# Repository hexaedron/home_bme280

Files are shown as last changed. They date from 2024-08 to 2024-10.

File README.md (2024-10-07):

# home_bme280

A small 3-in-one thermometer, barometer and gigrometer for indoor use.
Built with ch32v003 MCU, BME280 sensor and vk16k33 i2c 14-segment display modules.

## Usage
When powered on, the device starts cycling through 3 screens: Temperature in Celsius, Humidity and air pressure in mm Hg.
* To set the brightness, rotate the encoder.
* To set the screen change interval, press and hold the encoder for 2+ seconds, choose the desired interval from 5s to 60 min and then click it again.
* To force the immediate screen change, click the encoder.

## Assembly
Assembly is pretty straightforward. You should just note that PCB is a little bit redundant. A first my idea was to add an LDR resistor, but i've abandoned that idea later. So you can omit R_LDR and J_LDR. The firmware doesn't use them.
I've also made some extra pins availiable as J_EXT. Feel free to use them to extend functionality if you want.

## Build
You will need [ch32v00fun](https://github.com/cnlohr/ch32v003fun/) and [funny_libs](https://github.com/hexaedron/funny_libs) to build it. I prefer using official WCH toolchain. If you prefer using vanilla risc-v GCC, then remove `#define WCH_FAST_INTERRUPT_ENABLED` from `funny_defs.h`.

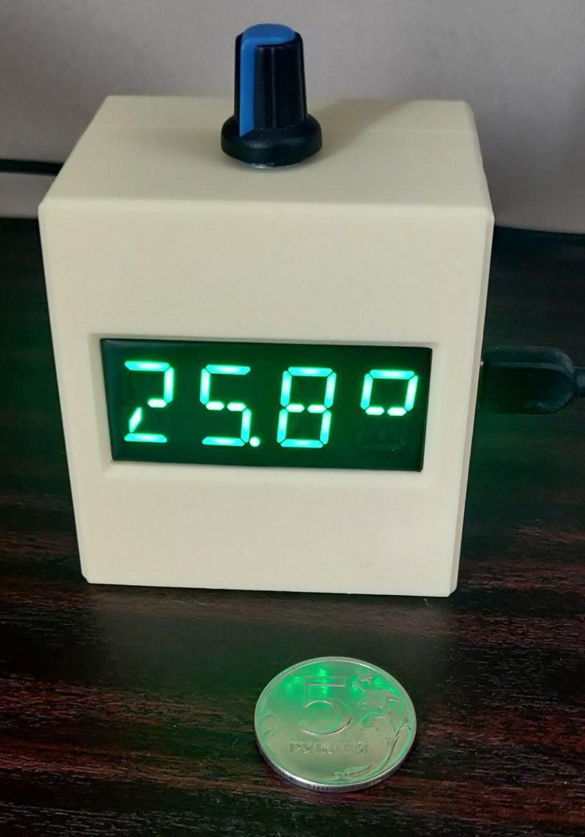
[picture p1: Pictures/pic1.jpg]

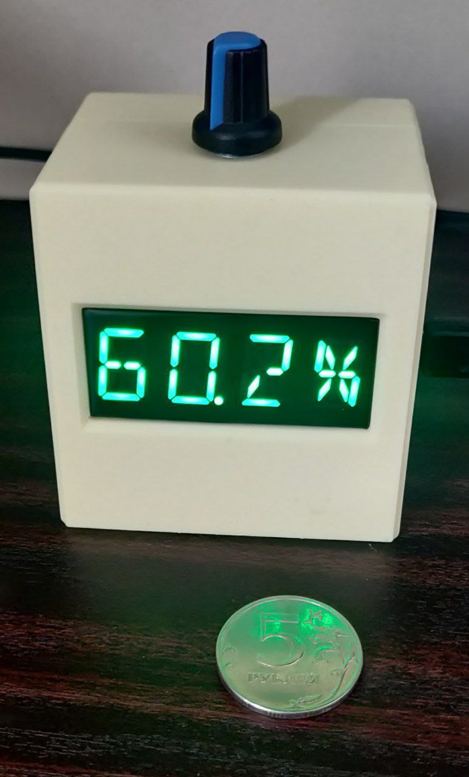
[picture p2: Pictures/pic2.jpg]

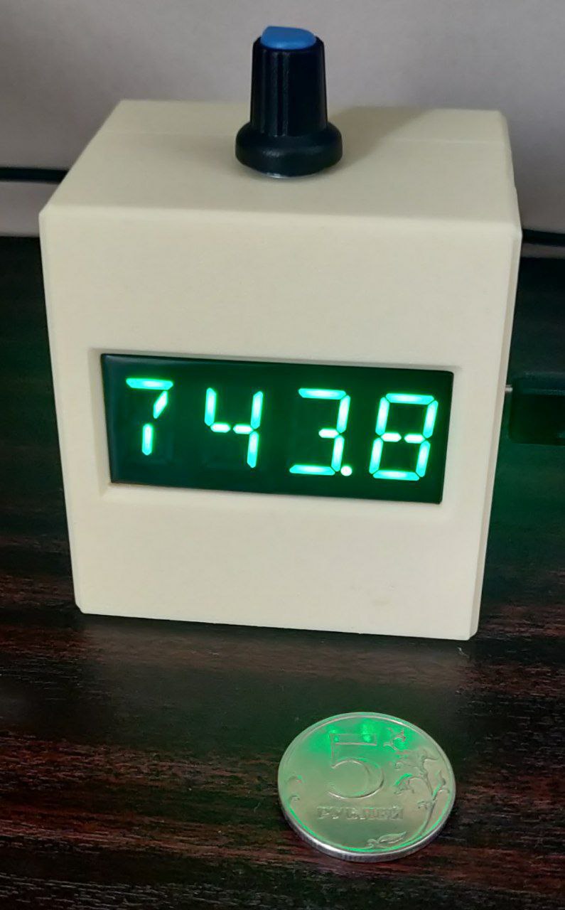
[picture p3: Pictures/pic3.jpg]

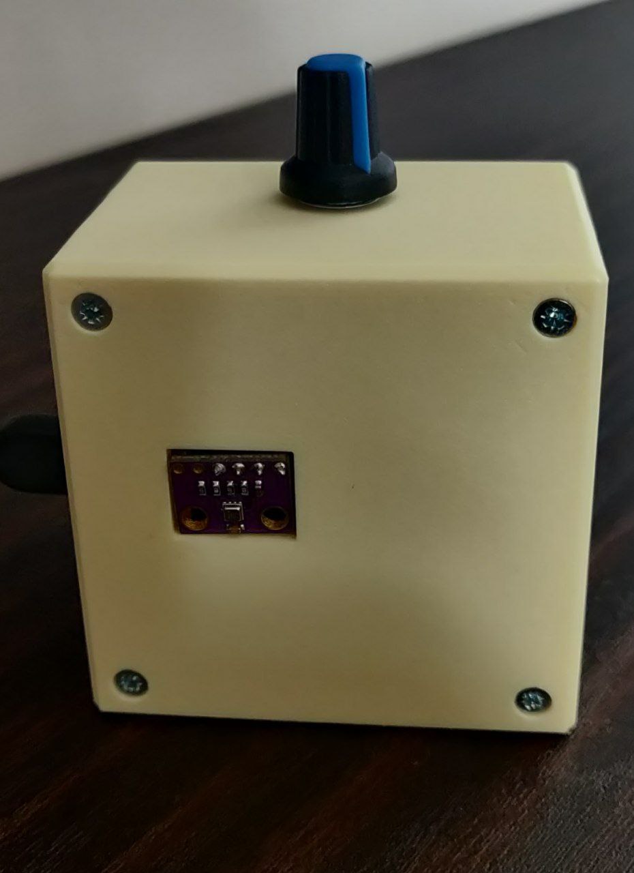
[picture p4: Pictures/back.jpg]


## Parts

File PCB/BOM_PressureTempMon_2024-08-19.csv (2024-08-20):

ID | Name | Designator | Footprint | Quantity | Manufacturer Part | Manufacturer | Supplier | Supplier Part | Price
1 | 10uF | C2,C6 | CASE-A_3216 | 2 | TCA1A106M8R | ROHM(罗姆) | LCSC | C184153 | 0.062
2 | 100nF | C5 | C1206 | 1 | C3216X7R2A104M160AA | TDK | LCSC | C3883507 | 0.455
3 | HDR-M-2.54_1x5 | ENCODER1,J_SCREEN | HDR-M-2.54_1X5 | 2 |  |  | LCSC | C358687 | 0.026
5 | HDR-M-2.54_1x2 | J_VCC | HDR-M-2.54_1X2 | 2 |  |  | LCSC | C124375 | 0.023
6 | HDR-M-2.54_1x3 | J_PRG1 | HDR-M-2.54_1X3 | 1 |  |  | LCSC | C180248 | 0.17
7 | HDR-M-2.54_1x4 | J_SENSOR | HDR-M-2.54_1X4 | 1 |  |  | LCSC | C124378 | 0.039
9 | CH32V003F4P6 | U5 | TSSOP-20_L6.5-W4.4-P0.65-LS6.4-BL | 1 | CH32V003F4P6 | null | LCSC | C5187096 | 0.258
10 | LM1117GS-3.3 | U_3 | SOT-223-3_L6.5-W3.4-P2.30-LS7.0-BR | 1 | LM1117GS-3.3 | HTC | LCSC | C411821 | 0.149
11 | Rotary encoder Arduino module (round),,,,,,,,

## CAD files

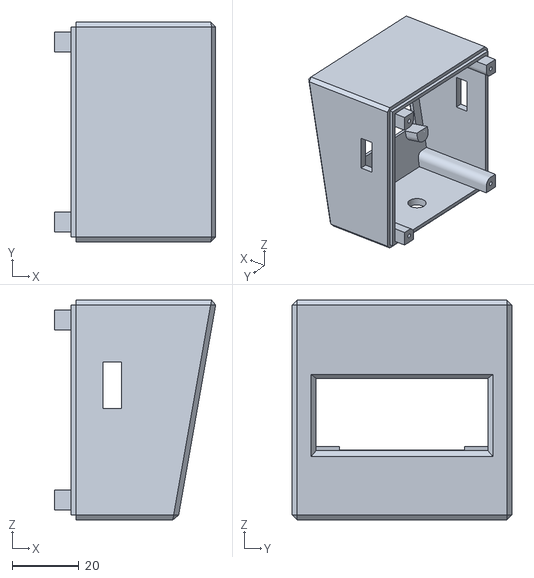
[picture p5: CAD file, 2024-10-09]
3DPrint/Front.stl
48.4 x 66.0 x 66.0

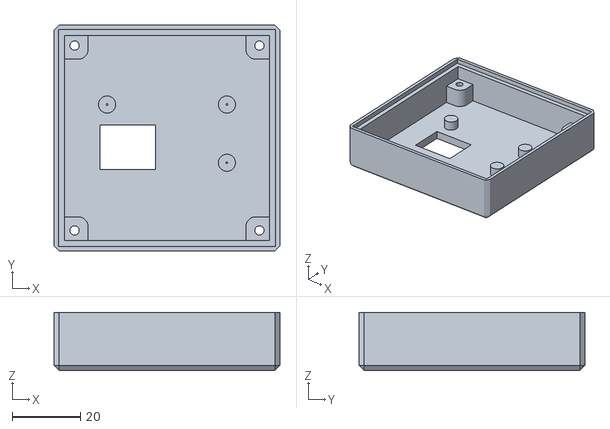
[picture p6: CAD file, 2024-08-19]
3DPrint/Back.stl
66.0 x 66.0 x 17.0

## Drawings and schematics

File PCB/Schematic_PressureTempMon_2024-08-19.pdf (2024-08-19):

# GND+⁵V

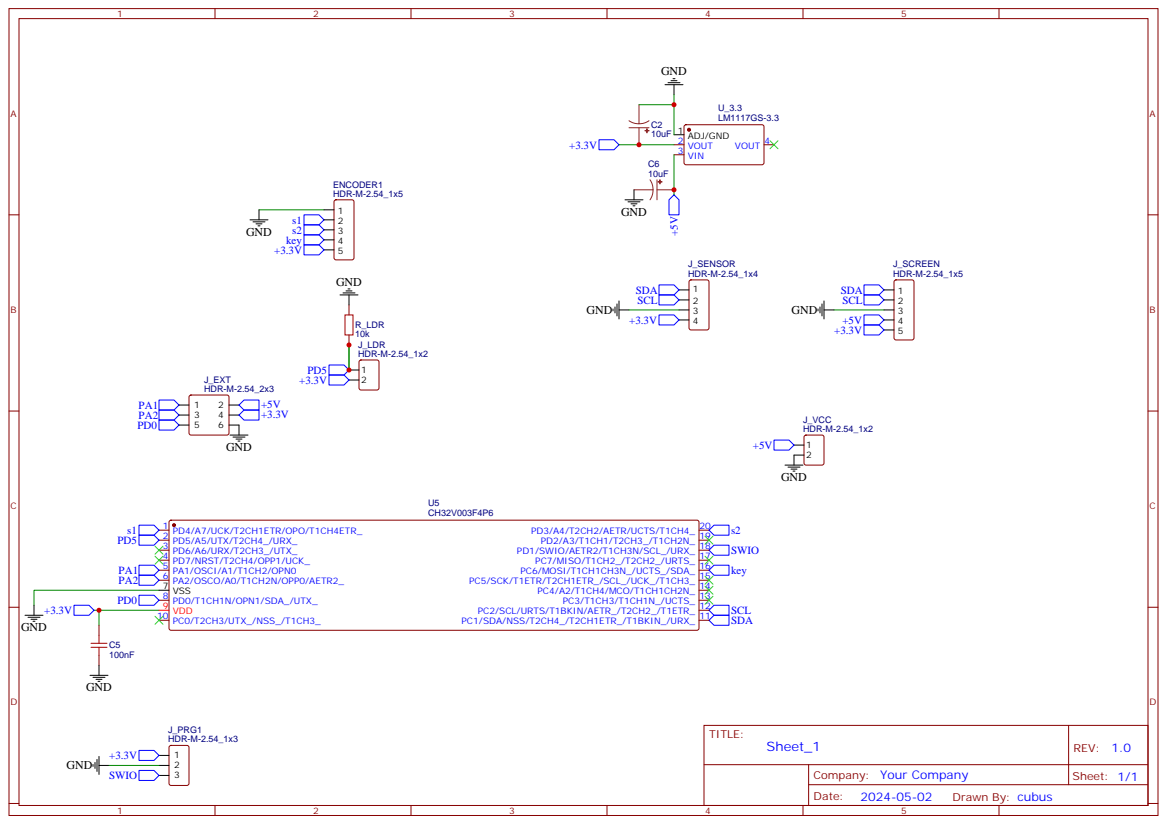
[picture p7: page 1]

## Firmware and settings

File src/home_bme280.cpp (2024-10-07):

#include <ch32v003fun.h>
#include "funny_defs.h"

#include "i2c_dma.h"
#include "BMP280.h"
#include "vk16k33.h"
#include "simpleTimer.h"
#include "tim2Encoder.h"
#include "optiondata.h"
#include "funny_time.h"

#include "pack_settings.h"

#include <stdbool.h>
#include <cstdlib>
#include <cstring>

enum displayMode_t
{
	printTemperature,
	printHumidity,
	printPressure
};

#define BRIGHTNESS_SAVE_TIMEOUT 5000UL
#define PRESSURE_HISTORY_HOURS  12

void setupMode(void);
int8_t getPressureTrend(uint32_t* pressureHistory, uint8_t pressureHistoryHours, uint32_t currentPressure);
void pushPressure(uint32_t* pressureHistory, uint8_t pressureHistoryHours, uint32_t currentPressure);

tim2Encoder enc(AFIO_PCFR1_TIM2_REMAP_NOREMAP);
vk16k33 screen;
uint16_t screenChangeSeconds_x5;
bool firstTime = true;

uint32_t pressureHistory[PRESSURE_HISTORY_HOURS] = {0};

int main()
{
	SystemInit();
#ifdef WCH_FAST_INTERRUPT_ENABLED
	__set_INTSYSCR(0x3); // [Experimental] enable fast interrupt feature
#endif
	system_initSystick();

	// We use button on PC6, so we need to init it and turn on interrupt.
	funGpioInitAll();
	funPinMode(PC6, GPIO_Speed_In | GPIO_CNF_IN_FLOATING);

	screenChangeSeconds_x5 = getScreenChangeSeconds_x5();

	bmp280 sensor;
	uint32_t pressure, humidity;
	int32_t temperature;

	// Accroding to vk16k33 datasheet, we need to wait until it wakes up.
	Delay_Ms(1); 

	I2C_init(400000, 0);

	sensor.init_default_params();
	sensor.init();

	screen.init();
	screen.setBrightness(getBrigtness());

	displayMode_t displayMode = displayMode_t::printTemperature;

	if( (screenChangeSeconds_x5 > 720) )
		screenChangeSeconds_x5 = 1;

	simpleTimer32 screenChangeTimer((uint32_t)screenChangeSeconds_x5 * 5000UL);
	simpleTimer32 flashTimer(BRIGHTNESS_SAVE_TIMEOUT);
	simpleTimer32 pressureHistoryTimer(3600UL * 1000UL);

	sensor.force_measurement();
	while (sensor.is_measuring())
	{
	};
	sensor.read_fixed();
	pressureHistory[PRESSURE_HISTORY_HOURS - 1] = sensor.getPressureMmHg();
	sensor.sleep();

	while (true)
	{
		keyTick();
		
		int delta = enc.getDelta();
		if(delta > 0)
		{
			screen.incBrightness();
			flashTimer.start_int();
		}
		if(delta < 0)
		{
			screen.decBrightness();
			flashTimer.start_int();
		}

		if(pressureHistoryTimer.ready())
		{
			sensor.force_measurement();
			while (sensor.is_measuring())
			{
			};
			sensor.read_fixed();
			pushPressure(pressureHistory, PRESSURE_HISTORY_HOURS, sensor.getPressureMmHg());
		}
		
		if(flashTimer.ready() && ((getBrigtness() != screen.getBrightness()) || (getScreenChangeSeconds_x5() != screenChangeSeconds_x5)))
		{
			uint8_t data0, data1;
			packSettings(screen.getBrightness(), screenChangeSeconds_x5, data0, data1);
			FlashOptionData(data0, data1);
			system_initSystick();
			screenChangeTimer.setPrd(screenChangeSeconds_x5 * 5000UL);
		}
		
		if(btnHeld())
		{
			setupMode();
		}

		bool wasClick = btnClick();
		if((screenChangeTimer.ready() || firstTime) || wasClick)
		{
			firstTime = false;
			if(wasClick) screenChangeTimer.start_int();
			wasClick = false;
			sensor.force_measurement();
			while (sensor.is_measuring())
			{
			};
			sensor.read_fixed();

			temperature = sensor.getTemp();
			humidity = sensor.getHumidity();
			pressure = sensor.getPressureMmHg();

			sensor.sleep();

			char buf[10];

			switch (displayMode)
			{
				case displayMode_t::printTemperature :
					itoa(temperature, buf, 10);
					if ((temperature > 0) && (temperature >= 1000))
					{
						screen.digit(ASCII_TO_INT(buf[0]), 0);
						screen.digit(ASCII_TO_INT(buf[1]), 1, true);
						screen.digit(ASCII_TO_INT(buf[2]), 2);
						screen.digit(10, 3);
					}
					else if((temperature > 0) && (temperature < 1000))
					{

						screen.digit(12, 0);
						screen.digit(ASCII_TO_INT(buf[0]), 1, true);
						screen.digit(ASCII_TO_INT(buf[1]), 2);
						screen.digit(10, 3);
					}
					screen.refresh();
					displayMode = displayMode_t::printHumidity;
				break;

				case displayMode_t::printHumidity :
					itoa(humidity, buf, 10);
					if(humidity >= 10000)
					{
						screen.digit(ASCII_TO_INT(buf[0]), 0);
						screen.digit(ASCII_TO_INT(buf[1]), 1, true);
						screen.digit(ASCII_TO_INT(buf[2]), 2);
					}
					else
					{
						screen.digit(12, 0);
						screen.digit(ASCII_TO_INT(buf[0]), 1, true);
						screen.digit(ASCII_TO_INT(buf[1]), 2);
					}
					screen.digit(11, 3);
					screen.refresh();
					displayMode = displayMode_t::printPressure;
				break;

				case  displayMode_t::printPressure :
					itoa(pressure / 256, buf, 10);
					screen.digit(ASCII_TO_INT(buf[0]), 0);
					screen.digit(ASCII_TO_INT(buf[1]), 1);
					screen.digit(ASCII_TO_INT(buf[2]), 2);
					switch (getPressureTrend(pressureHistory, PRESSURE_HISTORY_HOURS, pressure))
					{
						case 1:
							screen.digit(14, 3);
						break;

						case -1:
							screen.digit(13, 3);
						break;
					
						default:
							screen.digit(12, 3);
						break;
					}
					screen.refresh();
					displayMode = displayMode_t::printTemperature;
				break;
			
			default:
				break;
			}
		}
	}
}

void setupMode(void)
{
	simpleTimer32 refreshTimer(100UL);

	while (true)
	{
		keyTick();
		
		char buf[5];

		if(btnClick())
		{
			firstTime = true;
			return;
		}

		if(refreshTimer.ready())
		{
			uint8_t min = (screenChangeSeconds_x5 * 5) / 60;
			uint8_t sec = (screenChangeSeconds_x5 * 5) % 60;

			itoa(sec, buf, 10);
			if(sec > 0)
			{
				if(sec < 10)
				{
					screen.digit(0, 2);
					screen.digit(ASCII_TO_INT(buf[0]), 3);
				}
				else
				{
					screen.digit(ASCII_TO_INT(buf[0]), 2);
					screen.digit(ASCII_TO_INT(buf[1]), 3);
				}
			}
			else
			{
				screen.digit(ASCII_TO_INT(buf[0]), 2);
				screen.digit(ASCII_TO_INT(buf[0]), 3);
			}

			itoa(min, buf, 10);
			if(min < 10)
			{
				screen.digit(12, 0);
				screen.digit(ASCII_TO_INT(buf[0]), 1, true);
			}
			else
			{
				screen.digit(ASCII_TO_INT(buf[0]), 0);
				screen.digit(ASCII_TO_INT(buf[1]), 1, true);
			}

			screen.refresh();
		}

		int16_t delta = enc.getDelta();
		if(delta > 0)
		{
			if(screenChangeSeconds_x5 < 720)
			{
				screenChangeSeconds_x5++;
			}
		}
		else if (delta < 0)
		{
			if(screenChangeSeconds_x5 > 1)
			{
				screenChangeSeconds_x5--;
			}
		}
	}
}

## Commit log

2024-06-17 It shows temperature now
2024-06-18 Add pressure
2024-06-21 Add encoder
2024-06-21 Add button
2024-06-21 More precise screen timer behaviour
2024-08-19 Add PCB and case
    [BOM_PressureTempMon_2024-08-19.csv, Back.stl, Front.stl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]
2024-08-20 Add docs, pictures and firmware
    [BOM_PressureTempMon_2024-08-19.csv]
2024-09-03 Fix PCB
    [PCB_PressureTempMon_2024-09-03.pcbdoc]
2024-10-07 Add pressure trends
2024-10-07 New formware with pressure trends
2024-10-09 Fix pressure trend
2024-10-09 New case
    [Front.stl]
